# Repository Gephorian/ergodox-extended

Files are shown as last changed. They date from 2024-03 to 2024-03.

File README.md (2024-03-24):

# ErgoDox Extended

In a world where everyone is removing keys from their ErgoDox, I wanted more.

split keyboard
split keyboard from the side

My goals for this keyboard were to take my existing design from 2018 and remove the Teensy,
while making it more compact, a little more stylish, and with several options for cases in
mind.

pcb closeup

I used an ATMega32u4-au for the mcu because I wanted to be able to solder it by hand if I
needed. Same for the MCP23018-e/ss. I stuck with Mini-USB because, again, hand soldering.

There are options for SMD or through-hole diodes.

Cherry keyswitches, I've never used Gaterons or any others so I can't say whether they
would be compatible with the pcb.

This board works just like the original ErgoDox board; the same board can be used for
either half of the keyboard. Solder the logic components on the front, and diodes on the
front or back of the board. The silkscreen for diode direction is set up for `Row2Col` in
the firmware.

pcb render

Everything should be included in the kicad project aside from the firmware. Make sure
to clone recursively so that it pulls the submodule(s).

Firmware is [here](https://github.com/Gephorian/qmk_firmware/tree/ergodox-extended) until
I get a PR merged into QMK.

## Manufacturing

I've used JLCPCB and Elecrow. Both are great. Go for 1.6mm, whatever color you want is
fine. I was able to generate a BOM using JLCPCB's plugin and get it partially assembled,
so that takes a lot of guesswork out of the soldering and debugging if you go that route.

## Contributing

Feel free to submit PRs and issues for fixes.

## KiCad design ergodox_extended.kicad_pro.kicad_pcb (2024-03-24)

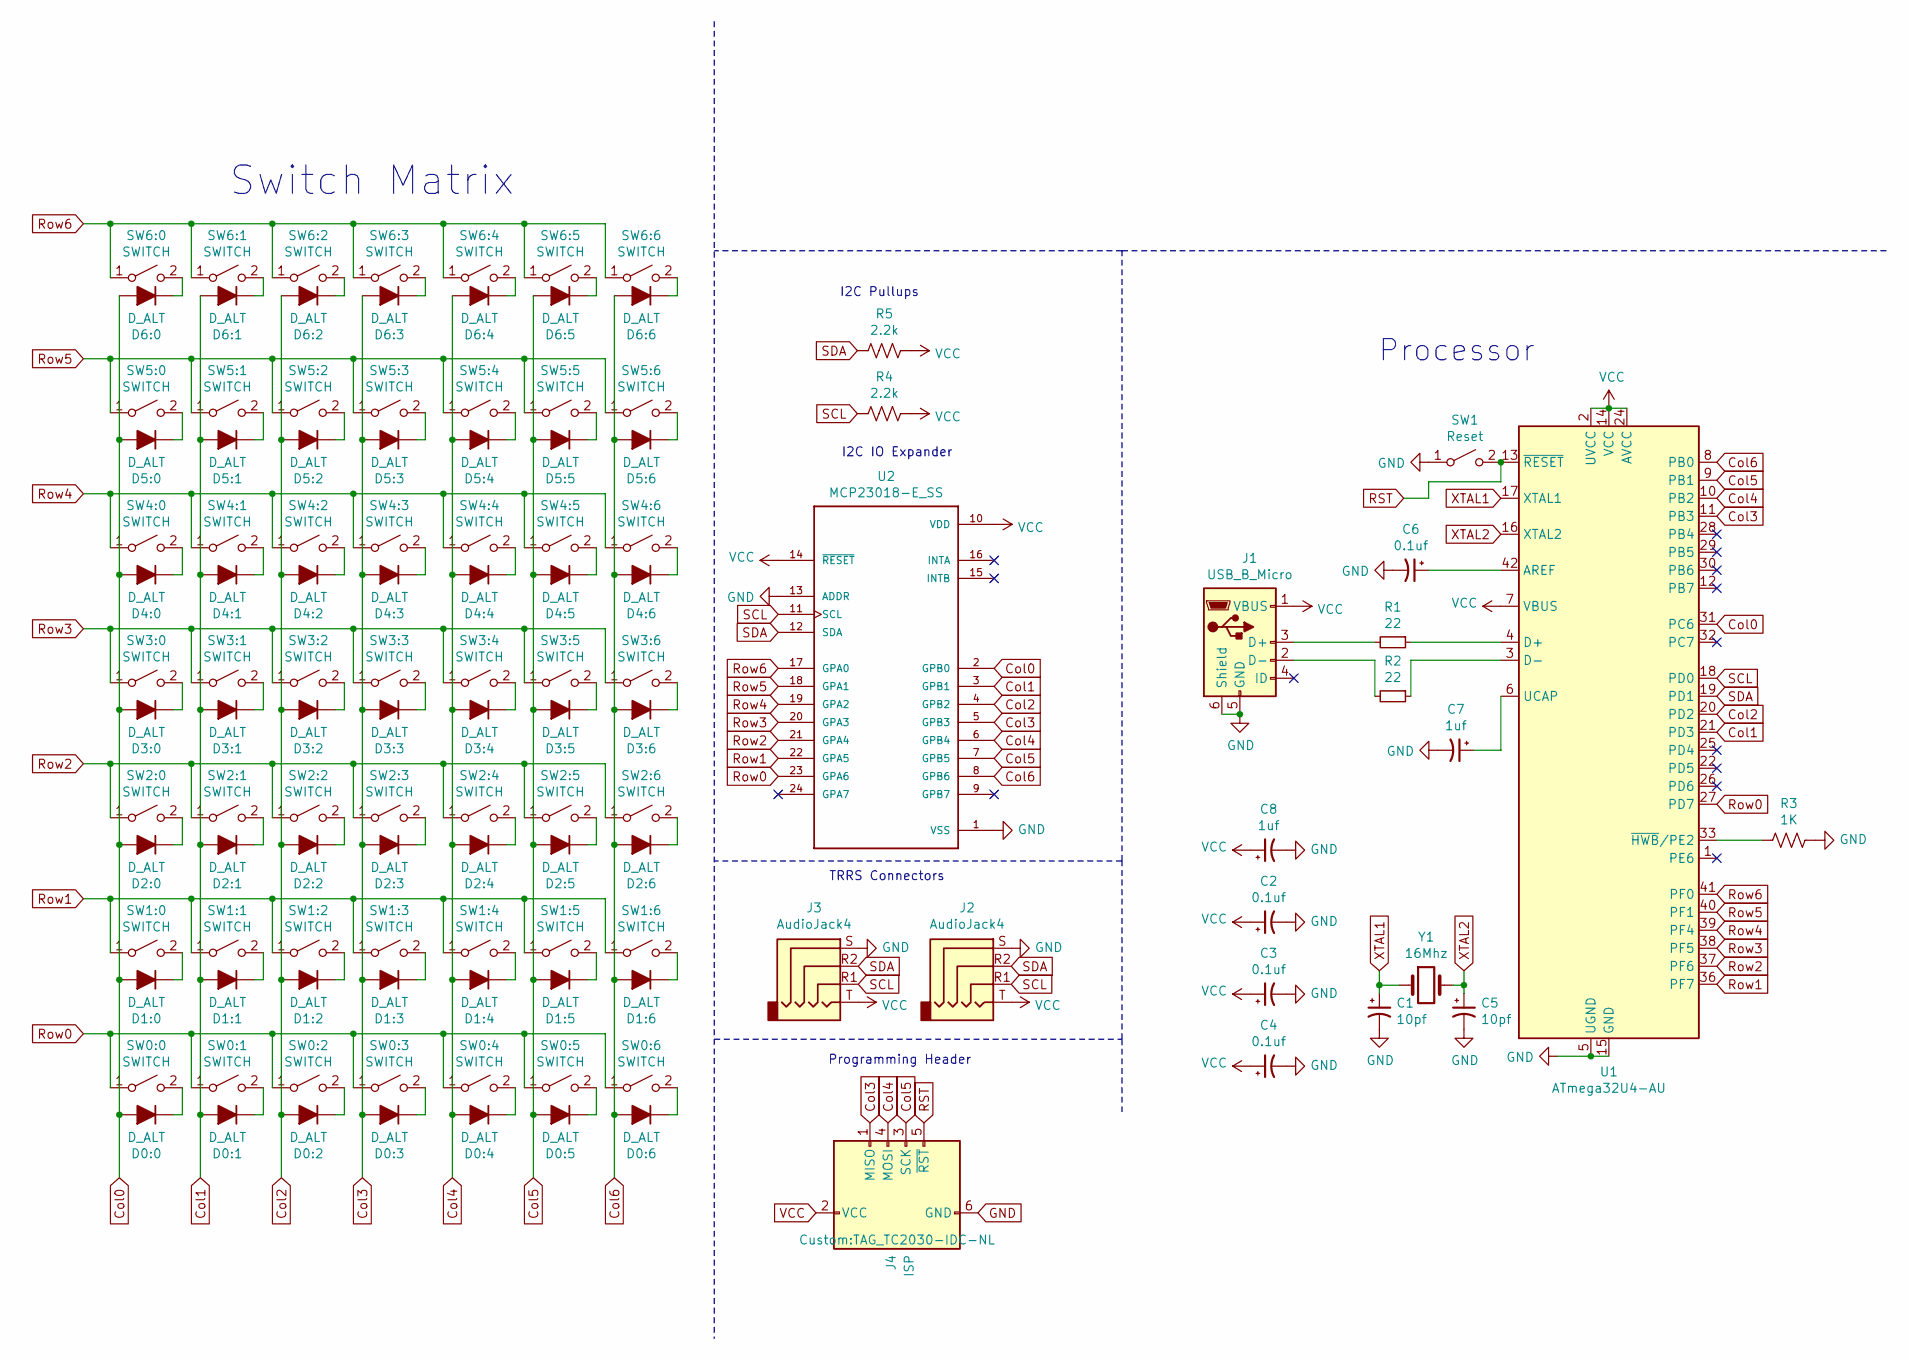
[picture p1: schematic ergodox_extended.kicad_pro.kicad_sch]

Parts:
C1, C5: 10pf; C_0402_1005Metric
C2, C3, C4, C6: 0.1uf; C_0603_1608Metric
C7, C8: 1uf; C_0805_2012Metric
D0:0, D0:1, D0:2, D0:3, D0:4, D0:5, D0:6, D1:0, D1:1, D1:2, D1:3, D1:4, D1:5, D1:6, D2:0, D2:1, D2:2, D2:3, D2:4, D2:5, D2:6, D3:0, D3:1, D3:2, D3:3, D3:4, D3:5, D3:6, D4:0, D4:1, D4:2, D4:3, D4:4, D4:5, D4:6, D5:0, D5:1, D5:2, D5:3, D5:4, D5:5, D5:6, D6:0, D6:1, D6:2, D6:3, D6:4, D6:5, D6:6: D_ALT; DIODE
J1: USB_B_Micro; USBMINImod
J2, J3: AudioJack4; SJ-43514-SMT
J4: ISP; TAG_TC2030-IDC-NL
R1, R2: 22; R_0805_2012Metric
R3: 1K; R_0805_2012Metric
R4, R5: 2.2k; R_0805_2012Metric
SW0:0, SW0:1, SW0:2, SW0:3, SW0:4, SW0:5, SW0:6, SW1:0, SW1:1, SW1:2, SW1:3, SW1:4, SW1:6, SW2:1, SW2:2, SW2:3, SW2:4, SW2:5, SW2:6, SW3:1, SW3:2, SW3:3, SW3:4, SW3:5, SW4:1, SW4:2, SW4:3, SW4:4, SW4:5, SW5:1, SW5:2, SW5:3, SW5:4, SW5:5, SW5:6, SW6:0, SW6:1, SW6:2, SW6:3, SW6:4, SW6:5, SW6:6: SWITCH; CHERRY_PCB_100H
SW1: Reset; SW_SPST_B3U-1100P
SW1:5: SWITCH; CHERRY_PCB_200H
SW2:0, SW3:0, SW3:6, SW4:0, SW4:6, SW5:0: SWITCH; CHERRY_PCB_150H
U1: ATmega32U4-AU; TQFP-44_10x10mm_P0.8mm
U2: MCP23018-E_SS; SOP65P780X200-24N
Y1: 16Mhz; Crystal_SMD_3225-4Pin_3.2x2.5mm

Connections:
Col0: D0:0.2 (A), D1:0.2 (A), D2:0.2 (A), D3:0.2 (A), D4:0.2 (A), D5:0.2 (A), D6:0.2 (A), U1.31 (PC6), U2.2 (GPB0)
Col1: D0:1.2 (A), D1:1.2 (A), D2:1.2 (A), D3:1.2 (A), D4:1.2 (A), D5:1.2 (A), D6:1.2 (A), U1.21 (PD3), U2.3 (GPB1)
Col2: D0:2.2 (A), D1:2.2 (A), D2:2.2 (A), D3:2.2 (A), D4:2.2 (A), D5:2.2 (A), D6:2.2 (A), U1.20 (PD2), U2.4 (GPB2)
Col3: D0:3.2 (A), D1:3.2 (A), D2:3.2 (A), D3:3.2 (A), D4:3.2 (A), D5:3.2 (A), D6:3.2 (A), J4.1 (MISO), U1.11 (PB3), U2.5 (GPB3)
Col4: D0:4.2 (A), D1:4.2 (A), D2:4.2 (A), D3:4.2 (A), D4:4.2 (A), D5:4.2 (A), D6:4.2 (A), J4.4 (MOSI), U1.10 (PB2), U2.6 (GPB4)
Col5: D0:5.2 (A), D1:5.2 (A), D2:5.2 (A), D3:5.2 (A), D4:5.2 (A), D5:5.2 (A), D6:5.2 (A), J4.3 (SCK), U1.9 (PB1), U2.7 (GPB5)
Col6: D0:6.2 (A), D1:6.2 (A), D2:6.2 (A), D3:6.2 (A), D4:6.2 (A), D5:6.2 (A), D6:6.2 (A), U1.8 (PB0), U2.8 (GPB6)
GND: C1.2, C2.2, C3.2, C4.2, C5.2, C6.2, C7.2, C8.2, J1.5 (GND), J1.6 (Shield), J2.S, J3.S, J4.6 (GND), R3.1, SW1.1 (A), U1.5 (UGND), U1.15 (GND), U1.23 (GND), U1.35 (GND), U1.43 (GND), U2.1 (VSS), U2.13 (ADDR); also elsewhere on the board
unnamed: D0:0.1 (K), SW0:0.2 (B)
unnamed: D0:1.1 (K), SW0:1.2 (B)
unnamed: D0:2.1 (K), SW0:2.2 (B)
unnamed: D0:3.1 (K), SW0:3.2 (B)
unnamed: D0:4.1 (K), SW0:4.2 (B)
unnamed: D0:5.1 (K), SW0:5.2 (B)
unnamed: D0:6.1 (K), SW0:6.2 (B)
unnamed: D1:0.1 (K), SW1:0.2 (B)
unnamed: D1:1.1 (K), SW1:1.2 (B)
unnamed: D1:2.1 (K), SW1:2.2 (B)
unnamed: D1:3.1 (K), SW1:3.2 (B)
unnamed: D1:4.1 (K), SW1:4.2 (B)
unnamed: D1:5.1 (K), SW1:5.2 (B)
unnamed: D1:6.1 (K), SW1:6.2 (B)
unnamed: D2:0.1 (K), SW2:0.2 (B)
unnamed: D2:1.1 (K), SW2:1.2 (B)
unnamed: D2:2.1 (K), SW2:2.2 (B)
unnamed: D2:3.1 (K), SW2:3.2 (B)
unnamed: D2:4.1 (K), SW2:4.2 (B)
unnamed: D2:5.1 (K), SW2:5.2 (B)
unnamed: D2:6.1 (K), SW2:6.2 (B)
unnamed: D3:0.1 (K), SW3:0.2 (B)
unnamed: D3:1.1 (K), SW3:1.2 (B)
unnamed: D3:2.1 (K), SW3:2.2 (B)
unnamed: D3:3.1 (K), SW3:3.2 (B)
unnamed: D3:4.1 (K), SW3:4.2 (B)
unnamed: D3:5.1 (K), SW3:5.2 (B)
unnamed: D3:6.1 (K), SW3:6.2 (B)
unnamed: D4:0.1 (K), SW4:0.2 (B)
unnamed: D4:1.1 (K), SW4:1.2 (B)
unnamed: D4:2.1 (K), SW4:2.2 (B)
unnamed: D4:3.1 (K), SW4:3.2 (B)
unnamed: D4:4.1 (K), SW4:4.2 (B)
unnamed: D4:5.1 (K), SW4:5.2 (B)
unnamed: D4:6.1 (K), SW4:6.2 (B)
unnamed: D5:0.1 (K), SW5:0.2 (B)
unnamed: D5:1.1 (K), SW5:1.2 (B)
unnamed: D5:2.1 (K), SW5:2.2 (B)
unnamed: D5:3.1 (K), SW5:3.2 (B)
unnamed: D5:4.1 (K), SW5:4.2 (B)
unnamed: D5:5.1 (K), SW5:5.2 (B)
unnamed: D5:6.1 (K), SW5:6.2 (B)
unnamed: D6:0.1 (K), SW6:0.2 (B)
unnamed: D6:1.1 (K), SW6:1.2 (B)
unnamed: D6:2.1 (K), SW6:2.2 (B)
unnamed: D6:3.1 (K), SW6:3.2 (B)
unnamed: D6:4.1 (K), SW6:4.2 (B)
unnamed: D6:5.1 (K), SW6:5.2 (B)
unnamed: D6:6.1 (K), SW6:6.2 (B)
unnamed: J1.3 (D+), R1.2
unnamed: J1.2 (D-), R2.2
unnamed: C6.1, U1.42 (AREF)
unnamed: R1.1, U1.4 (D+)
unnamed: R2.1, U1.3 (D-)
unnamed: C7.1, U1.6 (UCAP)
unnamed: R3.2, U1.33 (~HWB/PE2)
RST: J4.5 (~RST), SW1.2 (B), U1.13 (~RESET)
Row0: SW0:0.1 (A), SW0:1.1 (A), SW0:2.1 (A), SW0:3.1 (A), SW0:4.1 (A), SW0:5.1 (A), SW0:6.1 (A), U1.27 (PD7), U2.23 (GPA6)
Row1: SW1:0.1 (A), SW1:1.1 (A), SW1:2.1 (A), SW1:3.1 (A), SW1:4.1 (A), SW1:5.1 (A), SW1:6.1 (A), U1.36 (PF7), U2.22 (GPA5)
Row2: SW2:0.1 (A), SW2:1.1 (A), SW2:2.1 (A), SW2:3.1 (A), SW2:4.1 (A), SW2:5.1 (A), SW2:6.1 (A), U1.37 (PF6), U2.21 (GPA4)
Row3: SW3:0.1 (A), SW3:1.1 (A), SW3:2.1 (A), SW3:3.1 (A), SW3:4.1 (A), SW3:5.1 (A), SW3:6.1 (A), U1.38 (PF5), U2.20 (GPA3)
Row4: SW4:0.1 (A), SW4:1.1 (A), SW4:2.1 (A), SW4:3.1 (A), SW4:4.1 (A), SW4:5.1 (A), SW4:6.1 (A), U1.39 (PF4), U2.19 (GPA2)
Row5: SW5:0.1 (A), SW5:1.1 (A), SW5:2.1 (A), SW5:3.1 (A), SW5:4.1 (A), SW5:5.1 (A), SW5:6.1 (A), U1.40 (PF1), U2.18 (GPA1)
Row6: SW6:0.1 (A), SW6:1.1 (A), SW6:2.1 (A), SW6:3.1 (A), SW6:4.1 (A), SW6:5.1 (A), SW6:6.1 (A), U1.41 (PF0), U2.17 (GPA0)
SCL: J2.R1, J3.R1, R4.1, U1.18 (PD0), U2.11 (SCL)
SDA: J2.R2, J3.R2, R5.2, U1.19 (PD1), U2.12 (SDA)
VCC: C2.1, C3.1, C4.1, C8.1, J1.1 (VBUS), J2.T, J3.T, J4.2 (VCC), R4.2, R5.1, U1.2 (UVCC), U1.7 (VBUS), U1.14 (VCC), U1.24 (AVCC), U1.34 (VCC), U1.44 (AVCC), U2.10 (VDD), U2.14 (~RESET)
XTAL1: C1.1, U1.17 (XTAL1), Y1.1
XTAL2: C5.1, U1.16 (XTAL2), Y1.2

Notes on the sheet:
I2C Pullups
TRRS Connectors
Switch Matrix
Programming Header
I2C IO Expander
Processor

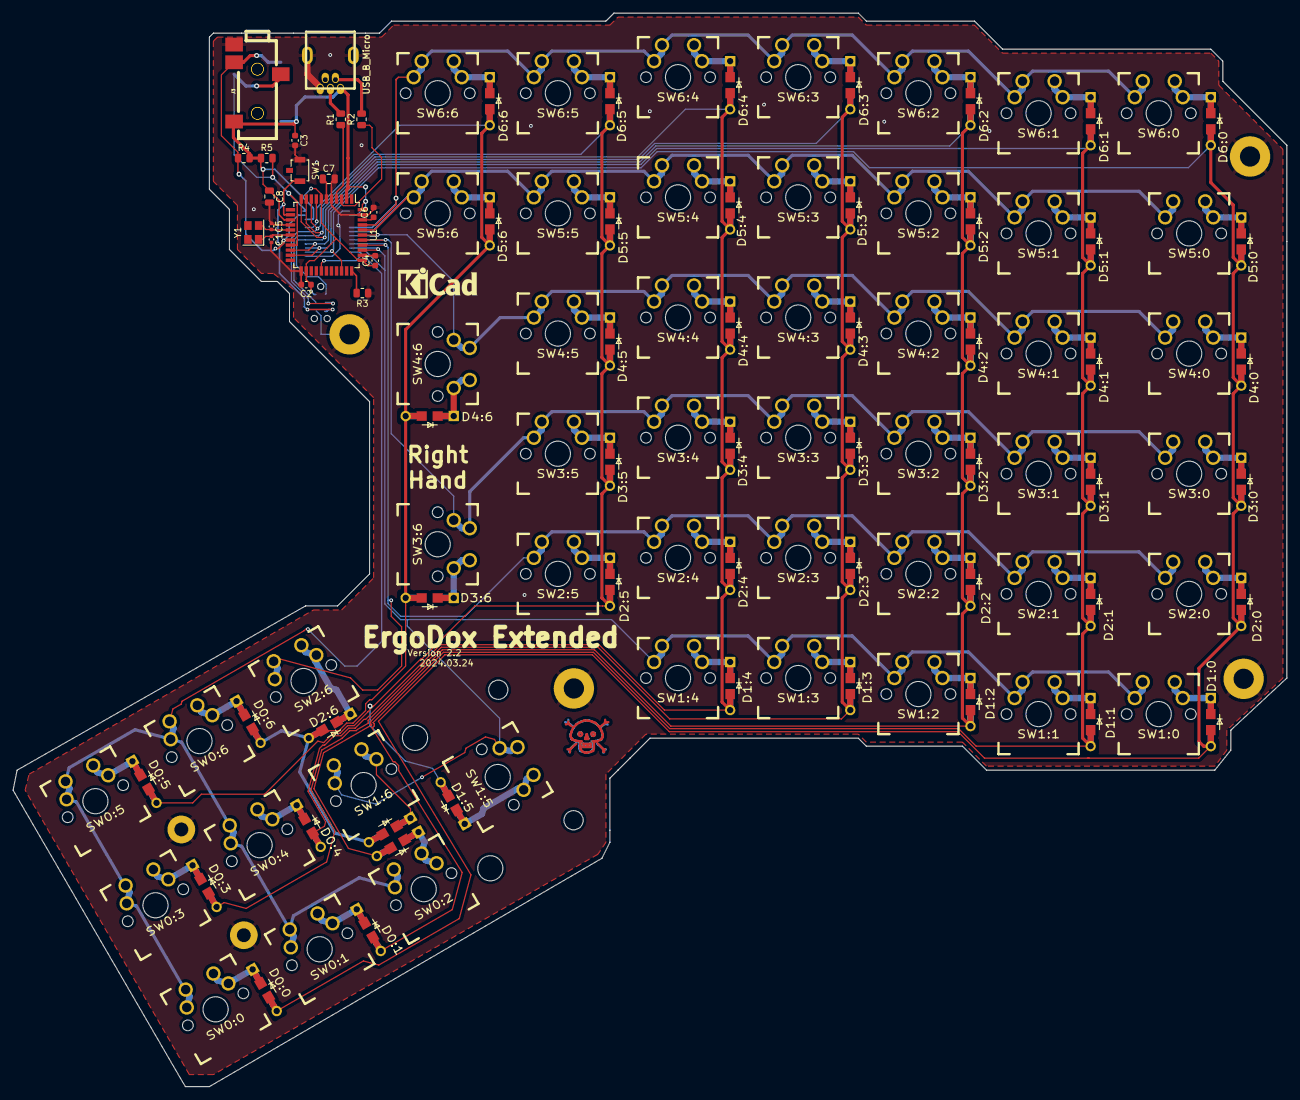
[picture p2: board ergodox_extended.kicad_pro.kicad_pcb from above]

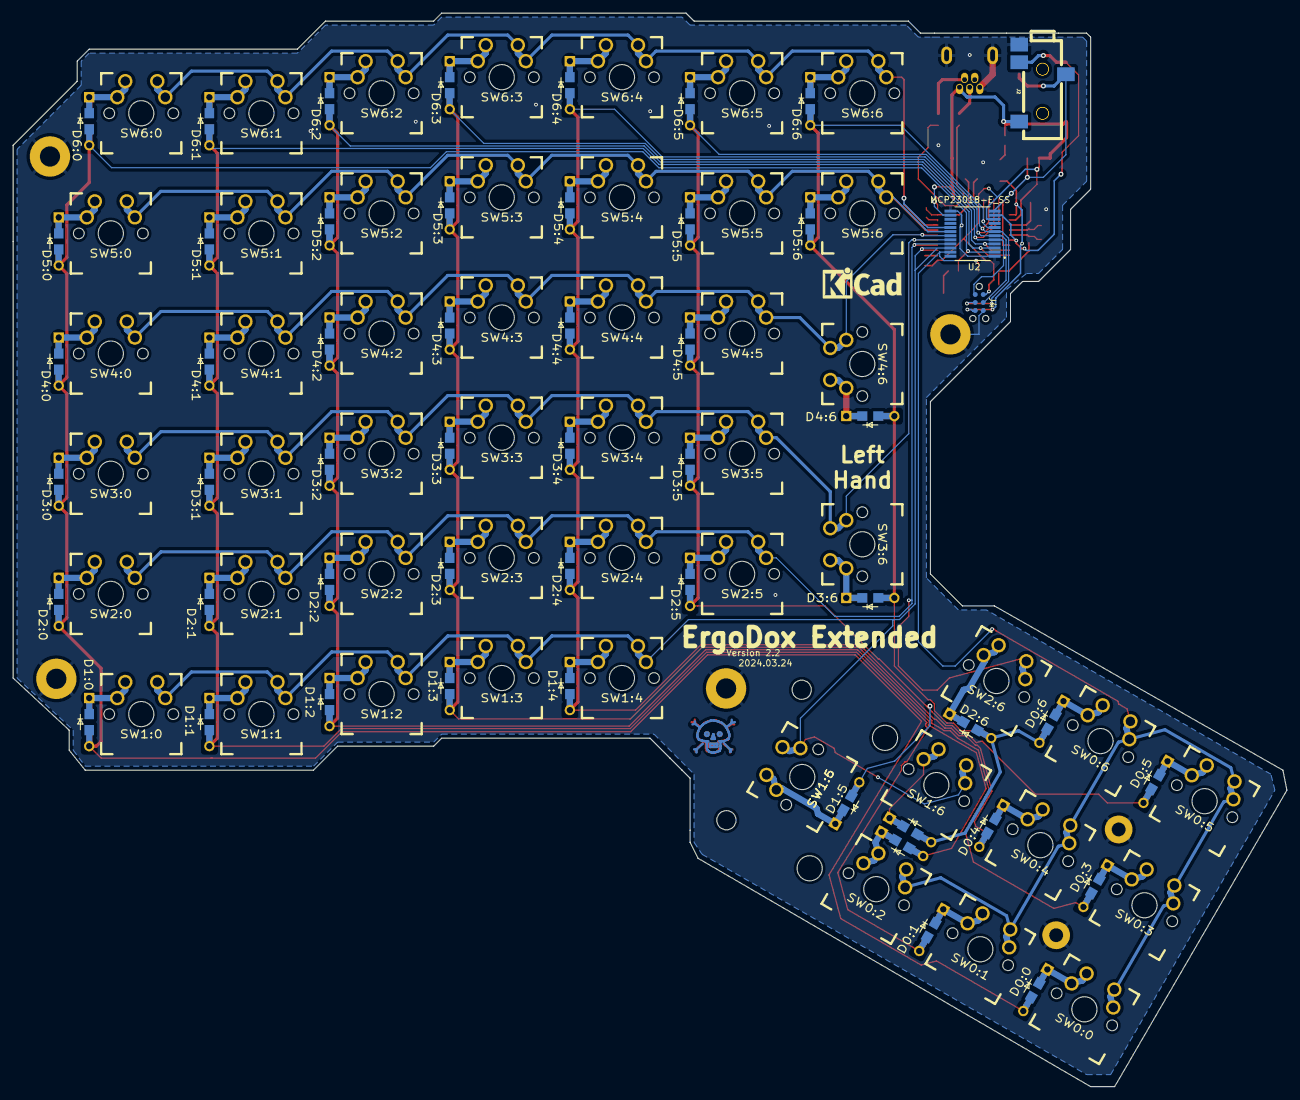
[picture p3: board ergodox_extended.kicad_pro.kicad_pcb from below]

Board: 2 copper layers, 201.9 x 170.2 mm, 125 parts (4 on the bottom side), 77 nets.

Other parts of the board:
MOUNT_1, MOUNT_2, MOUNT_3, MOUNT_4: MountingHole_3.2mm_M3_Pad
MOUNT_5, MOUNT_6: MountingHole_2.2mm_M2_Pad

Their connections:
GND: MOUNT_1.1, MOUNT_2.1, MOUNT_3.1, MOUNT_4.1, MOUNT_5.1, MOUNT_6.1; also elsewhere on the board
